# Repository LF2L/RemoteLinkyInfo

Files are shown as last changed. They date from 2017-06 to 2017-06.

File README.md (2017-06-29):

# RemoteLinkyInfo

## Description
Ecran déporté pour visualser les informations générées par le compteur Linky (trame générée par le compteur conecté Linky).
Alarme en cas de consommation critique par rapport au contrat souscrit.
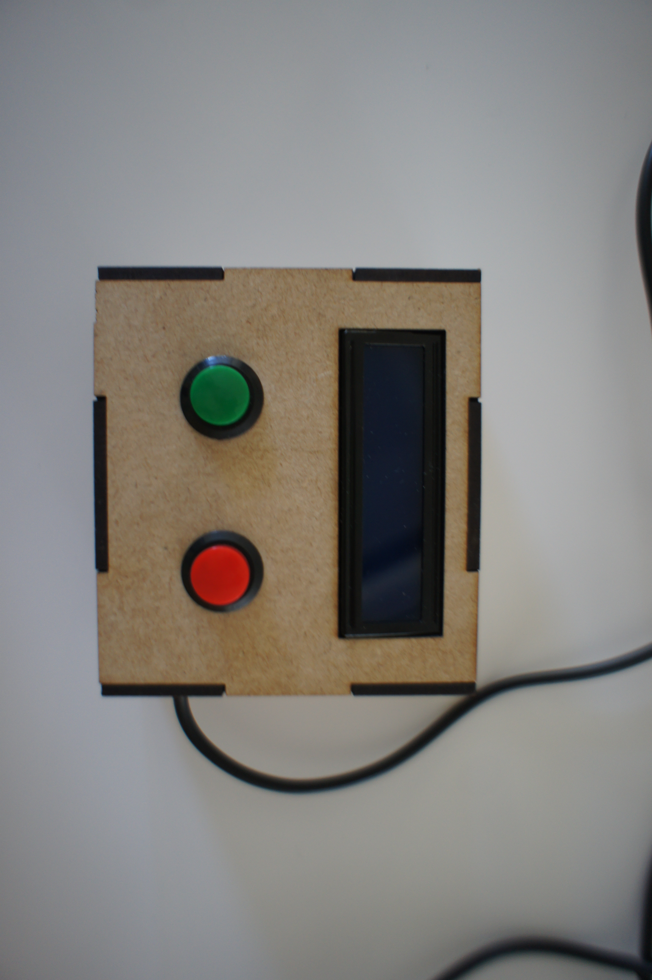
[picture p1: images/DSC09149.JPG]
remote Linky info exterieur

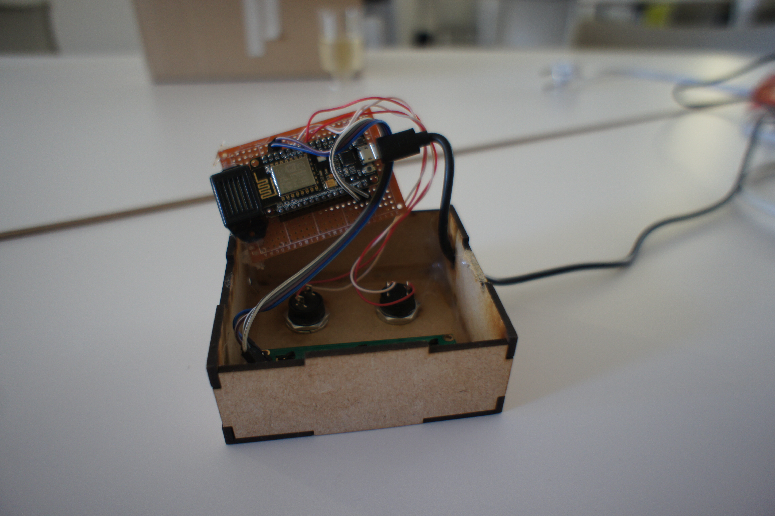
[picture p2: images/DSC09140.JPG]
remote Linky info interieur


## Fonctions
* Afficher les informations sur un écran LCD
* Bouton pour afficher les informations non affichées
* Alarme en cas de consommation critique par rapport au contrat souscrit.
* Bouton pour déclencher le délestage d’appareils consommateurs pas utile

## Composants
* Node MCU ESP8266
* écran LCD 16x2
* module I2C pour l'écran
* 2 boutons poussoirs
* 1 buzzer 
* 2 résistances 

## Schéma d'assemblage électronique
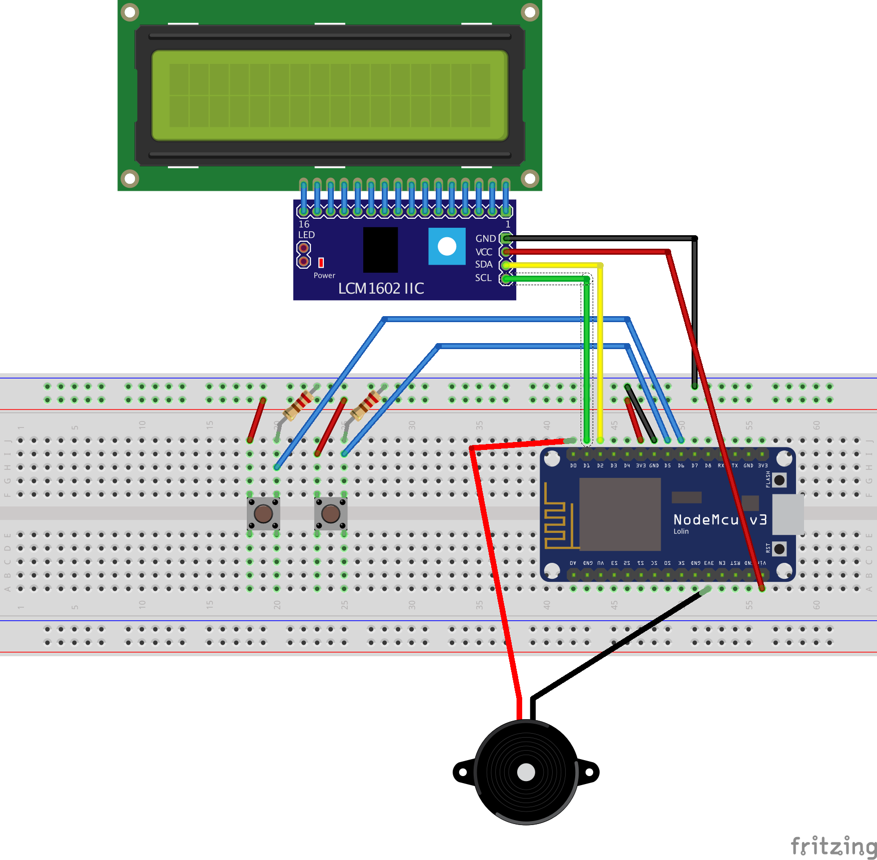
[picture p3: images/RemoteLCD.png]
schéma assemblage


## Boitiers 
* MDF 3mm

## Echanges d'informations
L'appareil va se connecter à un serveur qui centralise les informations concernant les objets connectés et le compteur Linky. Ce serveur stocke les informations concernants les objets connecté aisni que les informations produites par le compteur

### Informations récupérées 
L'écran déporter va interroger le serveur pour recuperer les informations suivantes au format JSON:
* IINST
* ISOUSC
* IMAX
* PTEC
* seuil

Pour plus de detail concernant les informations récupérées, reportez vous à la documentation technique ERDF-NOI-CPT_54E.
Le seuil est un variable modifiable sur le serveur qui permet d'ajuster le déclenchement de l'alarme et du délestage eventuel.

### Informations envoyées 
L'écran déporté envoie également des informations sur son état au serveur:
* IP
* id
* type d'objet connecté

### Fonctionnement
* Afficher les informations sur un écran LCD
L’écran déporté réalise une requête sur un service REST du serveur qui stock les informations du compteur pour recevoir les dernières information du compteur et les stocker localement jusqu’à la prochaine requête. Des informations peuvent être calculé par l’objet ou par le serveur qui envoie les informations (dépend de l’architecture de la bdd) . 
* Bouton pour déclencher le délestage d’appareils consommateurs pas utile
Réalise une requête sur le service REST fourni par le serveur local pour que celui ci envoie une requête aux objets connectés qui permette de contrôler la consommation.

## To do 
* Changer le mécanisme d’interaction avec le serveur : Envoie des informations de l’objet pour recevoir les informations du compteur
* Généraliser l’affichage des informations reçues. Pour le moment, les données attendues sont codées « en dur ».

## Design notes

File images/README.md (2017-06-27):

# Documentation de la prise RFID
* photographie du prototype
* schéma électronique

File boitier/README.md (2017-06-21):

# Boitier de l'écran déporté
Le boitier à été concu pour du MDF 3mm en utilisant le logiciel SolidWorks

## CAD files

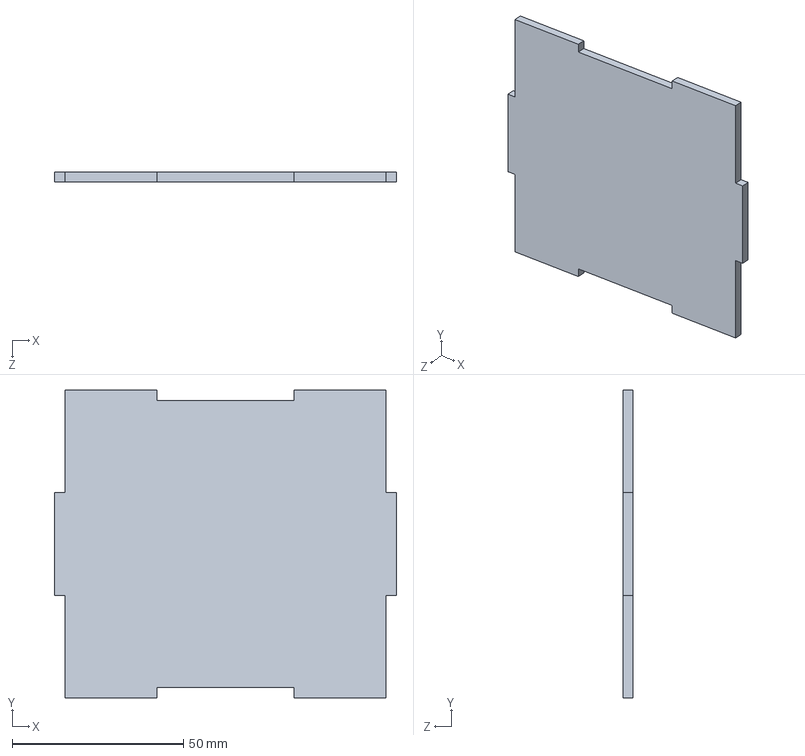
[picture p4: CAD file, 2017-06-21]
boitier/rear.SLDPRT
100.0 x 90.0 x 3.00 mm

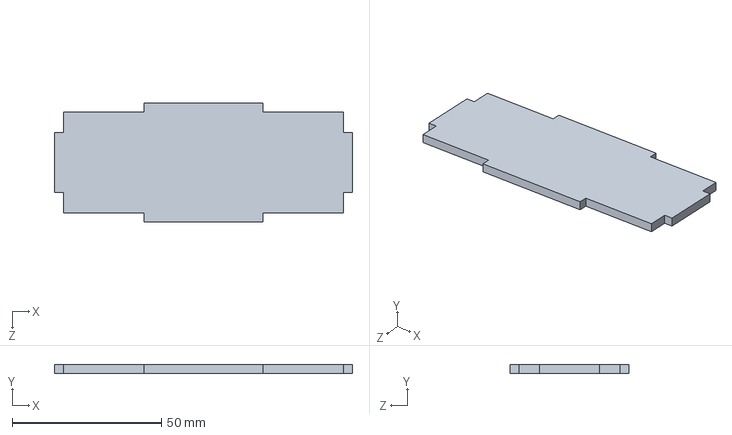
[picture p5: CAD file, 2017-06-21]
boitier/Top-Bottom.SLDPRT
100.0 x 3.00 x 40.0 mm

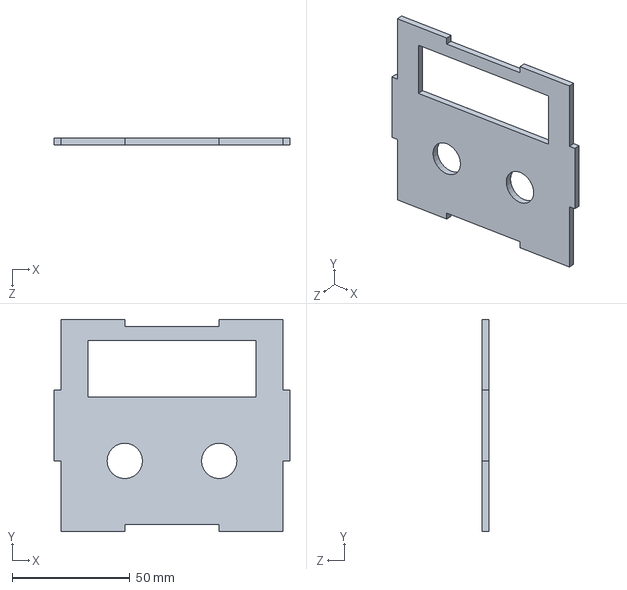
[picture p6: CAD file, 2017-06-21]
boitier/front.SLDPRT
100.0 x 90.0 x 3.00 mm

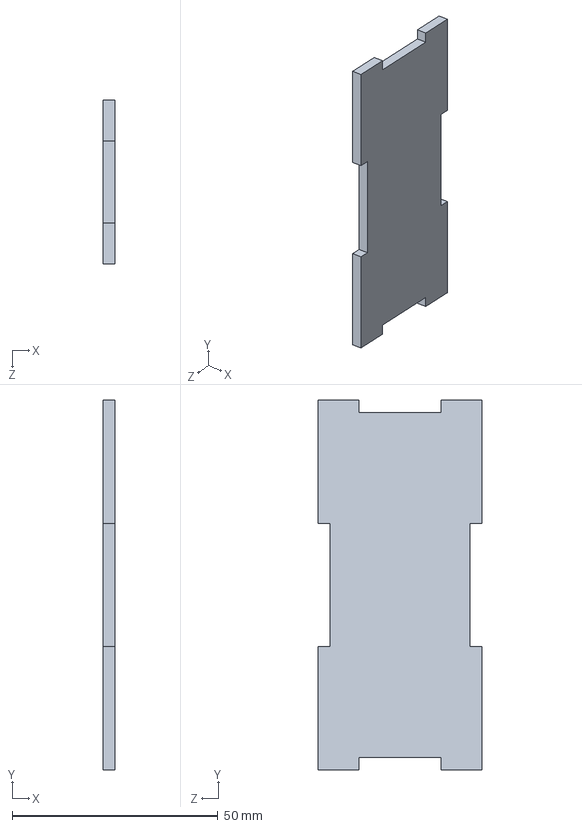
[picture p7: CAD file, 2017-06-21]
boitier/Left-Right.SLDPRT
3.00 x 90.0 x 40.0 mm

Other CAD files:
boitier/Left-Right.DXF
boitier/Top-Bottom.DXF
boitier/front.DXF
boitier/rear.DXF

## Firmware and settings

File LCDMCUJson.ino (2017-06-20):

#include <LiquidCrystal_I2C.h>
#include <ArduinoJson.h>

#include <Arduino.h>

#include <ESP8266WiFi.h>
#include <ESP8266WiFiMulti.h>

#include <ESP8266HTTPClient.h>

#define BUZZERPIN 16
#define BTNVERT 12
#define BTNROUGE 14

ESP8266WiFiMulti WiFiMulti;

const char* ssid = "IoE Server";
const char* password = "projetLinkyByMaker2017";
bool alarm = false;
int printedInfo =0;
int conCompte =0;
int compteurSendingIoTinf=0;


// Construct an LCD object and pass it the 
// I2C address, width (in characters) and
// height (in characters). Depending on the
// Actual device, the IC2 address may change.
LiquidCrystal_I2C lcd(0x3F, 16, 2);

struct IoTobject{
  IPAddress ip;
  char* id;
  char* device_type;
  
  void printconsole(){
     Serial.println("info into IoTObject ");
     Serial.print(" IP: ");
     Serial.println(ip);
     Serial.print(" id: ");
     Serial.println(id);
     Serial.print(" device: ");
     Serial.println(device_type);
  }
};
IoTobject monit;


struct InfoEnergie{
  int IINST;
  int ISOUSC; 
  int IMAX; 
  char PTEC[4]; 
  float seuil = 0.9;
  
  void printconsole(){
    Serial.println("info InfoEnergie ");
     Serial.print(" IINST: ");
     Serial.println(IINST);
     Serial.print(" ISOUSC: ");
     Serial.println(ISOUSC);
     Serial.print(" IMAX: ");
     Serial.println(IMAX);
     Serial.print(" PTEC: ");
     Serial.println(PTEC);
     Serial.print(" seuil: ");
     Serial.println(seuil);
  }
};
InfoEnergie infoEnergie;

HTTPClient http;

void setup() {
   Serial.begin(9600);
  while (!Serial) {
    // wait serial port initialization
  }
  for(uint8_t t = 4; t > 0; t--) {
        Serial.printf("[SETUP] WAIT %d...\n", t);
        Serial.flush();
        delay(1000);
    }

    WiFiMulti.addAP("IoE Server", "projetLinkyByMaker2017");

  // The begin call takes the width and height. This
  // Should match the number provided to the constructor.
  lcd.begin(16,2);
  lcd.init();

  // Turn on the backlight.
  lcd.backlight();
  
  pinMode(BUZZERPIN, OUTPUT);
  pinMode(BTNVERT, INPUT);
  pinMode(BTNROUGE, INPUT);

 monit.ip=WiFi.localIP();
 monit.device_type = "monitor";
 monit.id="00001";
 
}

void loop() {
  if(compteurSendingIoTinf == false){
      compteurSendingIoTinf=sendIotInfo();
  }
  //monit.printconsole();
   if((WiFiMulti.run() == WL_CONNECTED)) {
        
        http.begin("http://192.168.42.1:5000/monitoring/");
        int httpCode = http.GET();
        if(httpCode > 0) {
            // HTTP header has been send and Server response header has been handled
            Serial.printf("[HTTP] GET monitoring code: %d\n", httpCode);

            // file found at server
            if(httpCode == HTTP_CODE_OK) {
                String payload = http.getString();
                //Serial.println(payload);
                JSONparsing(payload);
                /*String inputest = "{\"IINST\": 15, \"PTEC\": \"HPJR\", \"ISOUSC\": 45, \"IMAX\": 90}"; 
                JSONparsing(inputest);*/
                printScreen();
                delestage();
            }
        } else {
            //Serial.printf("[HTTP] GET... failed, error: %s\n", http.errorToString(httpCode).c_str());
            lcd.setCursor(0, 0);
            lcd.print("error:          ");
            lcd.setCursor(0, 1);
            lcd.print("con. failed     ");
        }

        http.end();
    }
}

void JSONparsing(String stg){
  int beginningJSON = stg.indexOf('{');
  int endJSON = stg.lastIndexOf('}')+1;
  String jsonAlone=stg.substring(beginningJSON,endJSON);
  jsonAlone.replace("&#34;","\"");
  const size_t bufferSize = JSON_OBJECT_SIZE(5) + 60;
  DynamicJsonBuffer jsonBuffer(bufferSize);
  //Serial.print(stg.substring(beginningJSON,endJSON));
  JsonObject& root = jsonBuffer.parseObject(jsonAlone);
  //JsonObject& root = jsonBuffer.parseObject(inputest);

  // Test if parsing succeeds.
  if (!root.success()) {
    Serial.println("parseObject() failed");
    return;
  }
  infoEnergie.IINST = root["IINST"]; // "000"
  infoEnergie.ISOUSC = root["ISOUSC"]; // "00"
  infoEnergie.IMAX = root["IMAX"]; // "00"
  //infoEnergie.printconsole();
}

void printScreen(){

  switch(printedInfo){
    case 0:
    lcd.setCursor(0, 0);
    lcd.print("IINST           ");
    lcd.setCursor(10, 0);
    lcd.print(infoEnergie.IINST);
    lcd.setCursor(0, 1);
    lcd.print("ISOUSC          ");
    lcd.setCursor(10, 1);
    lcd.print(infoEnergie.ISOUSC);
    break;
    case 1:
    lcd.setCursor(0, 0);
    lcd.print("ISOUSC          ");
    lcd.setCursor(10, 0);
    lcd.print(infoEnergie.ISOUSC);
    lcd.setCursor(0, 1);
    lcd.print("IMAX            ");
    lcd.setCursor(10, 1);
    lcd.print(infoEnergie.IMAX);
    break;
    case 2:
    lcd.setCursor(0, 0);
    lcd.print("IMAX            ");
    lcd.setCursor(10, 0);
    lcd.print(infoEnergie.IMAX);
    lcd.setCursor(0, 1);
    lcd.print("                ");
    //lcd.setCursor(10, 1);
    //lcd.print(infoEnergie.ISOUSC);
    break;
  }
  if(digitalRead(BTNVERT) == HIGH){
    printedInfo +=1;
    if(printedInfo>2){
      printedInfo = 0;
    }
  }
}
void delestage(){
  long calcul =  infoEnergie.ISOUSC*infoEnergie.seuil;
  //Serial.println(calcul);
  if(infoEnergie.IINST >= calcul){
    alarm = true;
  }else{
    alarm = false;
  }
  
  if(alarm == true){
    digitalWrite(BUZZERPIN, HIGH);
  }else{
    digitalWrite(BUZZERPIN, LOW);
  }
  
  if(alarm == true && digitalRead(BTNROUGE) == HIGH){
    http.begin("http://192.168.42.1:5000/delesting/");
    int delestingReqCode = http.GET();
    if(delestingReqCode > 0) {
      Serial.printf("[HTTP] GET delesting code: %d\n", delestingReqCode);
      if(delestingReqCode == HTTP_CODE_OK) {
        for(int i; i<=1000;i++){
          lcd.setCursor(0, 0);
          lcd.print("Delestage       ");
          lcd.setCursor(0, 0);
          lcd.print("en cours        ");
        }
      }
    }
  }
}
bool sendIotInfo(){
  http.begin("http://192.168.42.1:5000/objectport/");
  http.addHeader("Content-Type", "application/json");
  /*String s= "{\"ip_adress\": ";
  s+=monit.ip;
  s+=", \"id\": ";
  s+=monit.id;
  s+=",\"device_type\": ";
  s+=monit.device_type;
  s+="}";
  int postCode = http.POST(s);*/
   int postCode = http.POST("{\"ip_adress\": \"192.168.42.17\", \"id\": \"00001\",\"device_type\": \"monitor\"}");
  http.writeToStream(&Serial);
  if (postCode == HTTP_CODE_OK){
    return true; 
  }else{
    return false;
  }
}

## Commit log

2017-06-20 Arduino files
2017-06-21 fichiers de conception et de découpage
    [Left-Right.DXF, Left-Right.SLDPRT, Top-Bottom.DXF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]
